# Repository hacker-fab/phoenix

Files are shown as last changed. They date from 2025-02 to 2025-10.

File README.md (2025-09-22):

# phoenix

Phoenix is a tube furnace used for thermal oxidation and annealing.

It uses PID control to follow custom temperature profiles and works on both MicroPython on the ESP32 and a simulated Python desktop environment.

<table>
  <tr>
    <td>
      <br>
      <sub>Fig 1. Tube furnace in action</sub>
    </td>
    <td>
      <br>
      <sub>Fig 2. Simulated PID following a heat profile</sub>
    </td>
    <td>
      <br>
      <sub>Fig 3. Controlling ramp rate to prevent thermal shock</sub>
    </td>
  </tr>
</table>

# Python setup
```bash
python3 -m venv .venv
source .venv/bin/activate
pip install -r requirements.txt
```

# Micropython setup

Install micropython
```bash
https://github.com/micropython/micropython/tree/master/ports/unix#readme
```

Install `typing`
```bash
micropython -m mip install github:josverl/micropython-stubs/mip/typing.mpy
```

Install `udataclasses`
```bash
cd ~/.micropython/lib
# extract src/udataclasses
git clone https://github.com/dhrosa/udataclasses.git tmp
mv tmp/src/udataclasses .
rm -rf tmp
```

# Flash code
```
esptool erase-flash
esptool --baud 460800 write-flash 0 images/ESP32_GENERIC_S3-SPIRAM_OCT-20250809-v1.26.0.bin

mpremote
mpremote connect /dev/ttyUSB0 fs cp main.py :
```
- use the UART port (left side) for flashing
- use the USB port (right side) when using mpremote

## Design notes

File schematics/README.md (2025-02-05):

Reverse engineered schematic based on the code from ProjectsInFlight

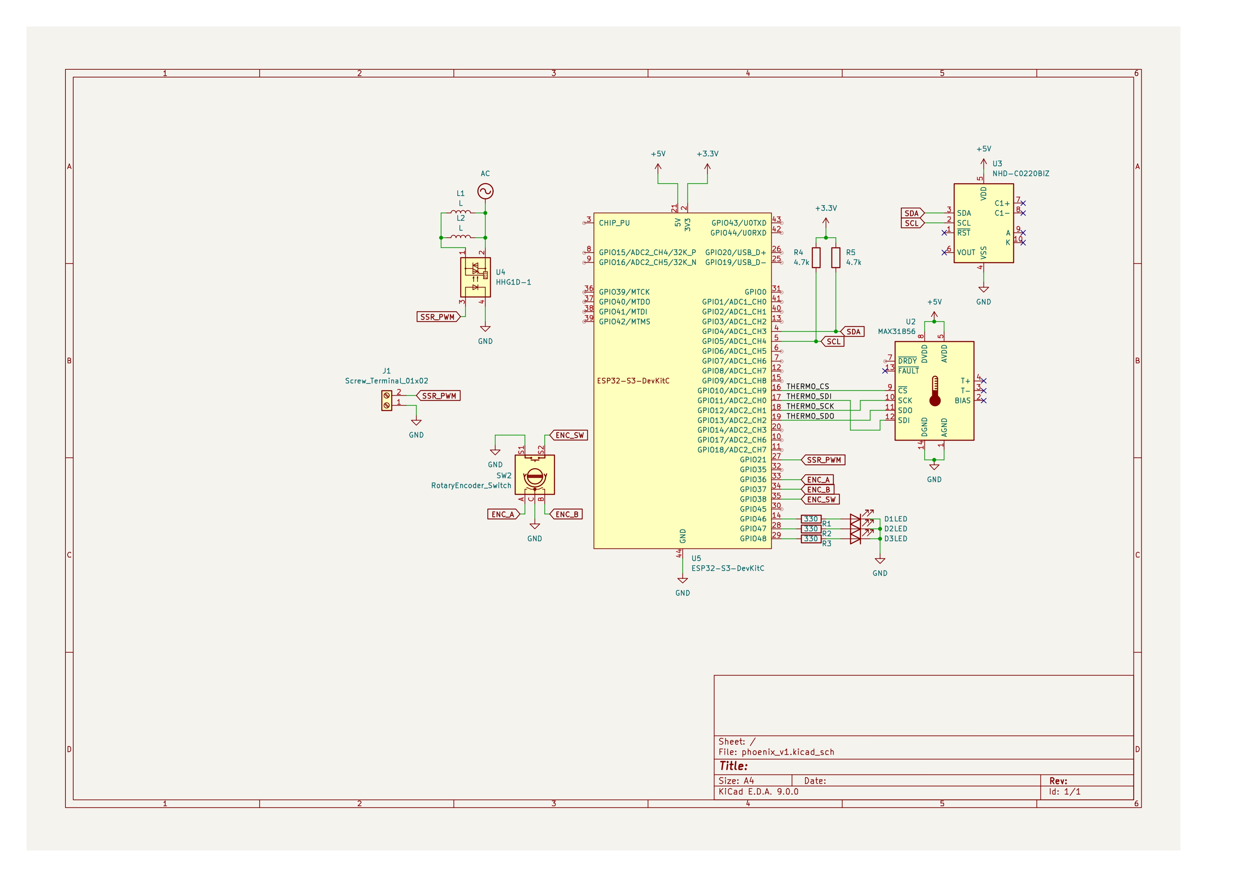
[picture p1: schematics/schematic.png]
schematic image


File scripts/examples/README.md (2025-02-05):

These mini test programs were written while electronics assembly.

1. LCD display.
2. Rotary encoder
    - On press => "button pressed" displayed on LCD.
    - On rotation => value displayed.
3. Thermocouple test
    - should print temp values in Serial console.

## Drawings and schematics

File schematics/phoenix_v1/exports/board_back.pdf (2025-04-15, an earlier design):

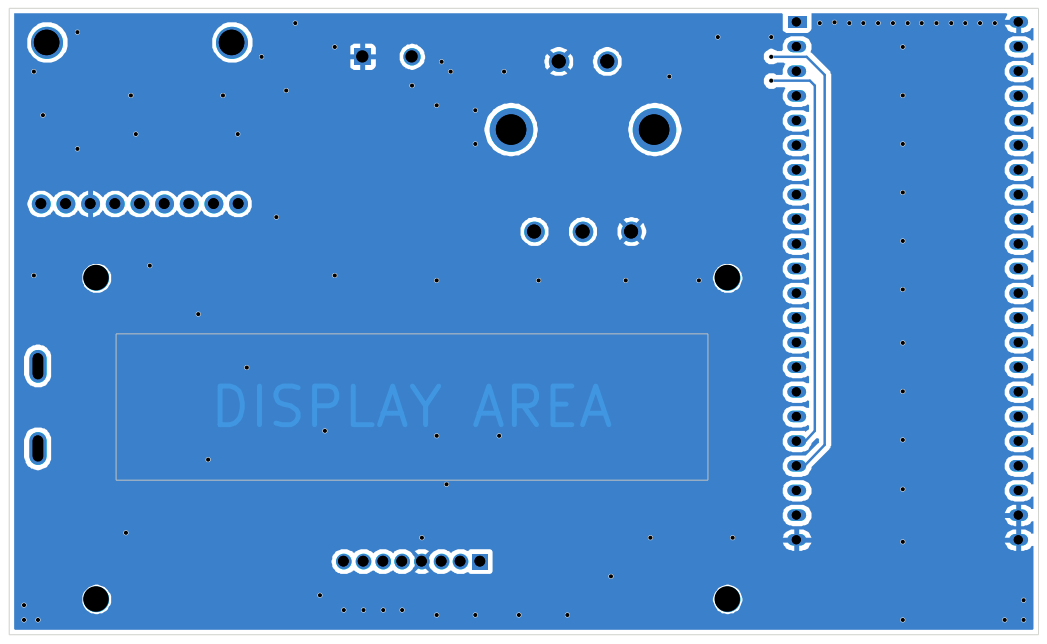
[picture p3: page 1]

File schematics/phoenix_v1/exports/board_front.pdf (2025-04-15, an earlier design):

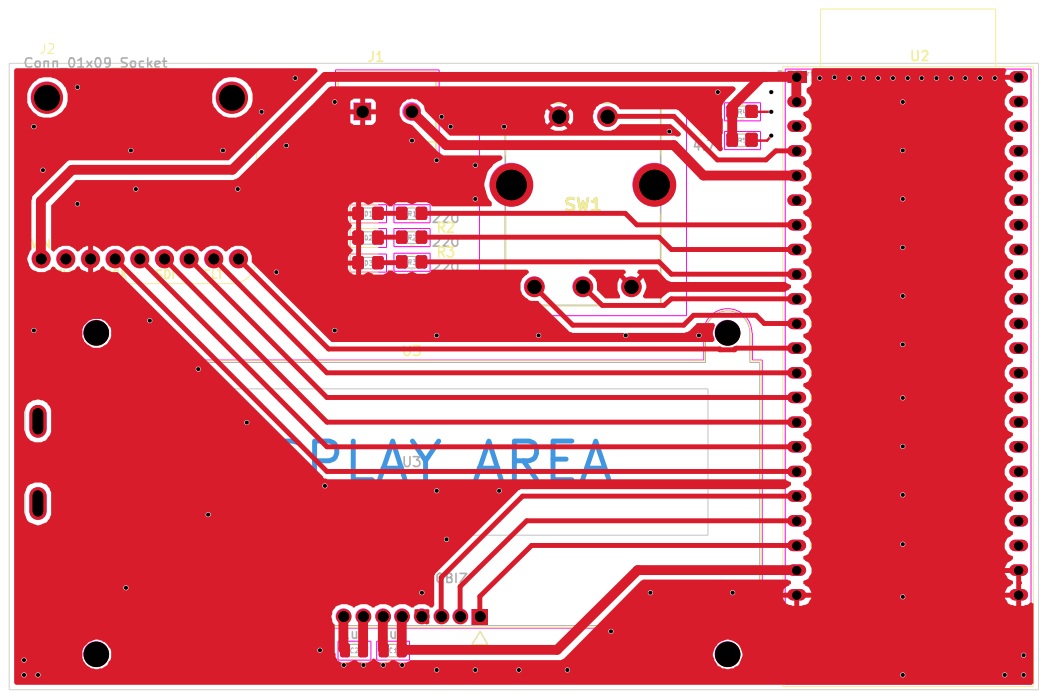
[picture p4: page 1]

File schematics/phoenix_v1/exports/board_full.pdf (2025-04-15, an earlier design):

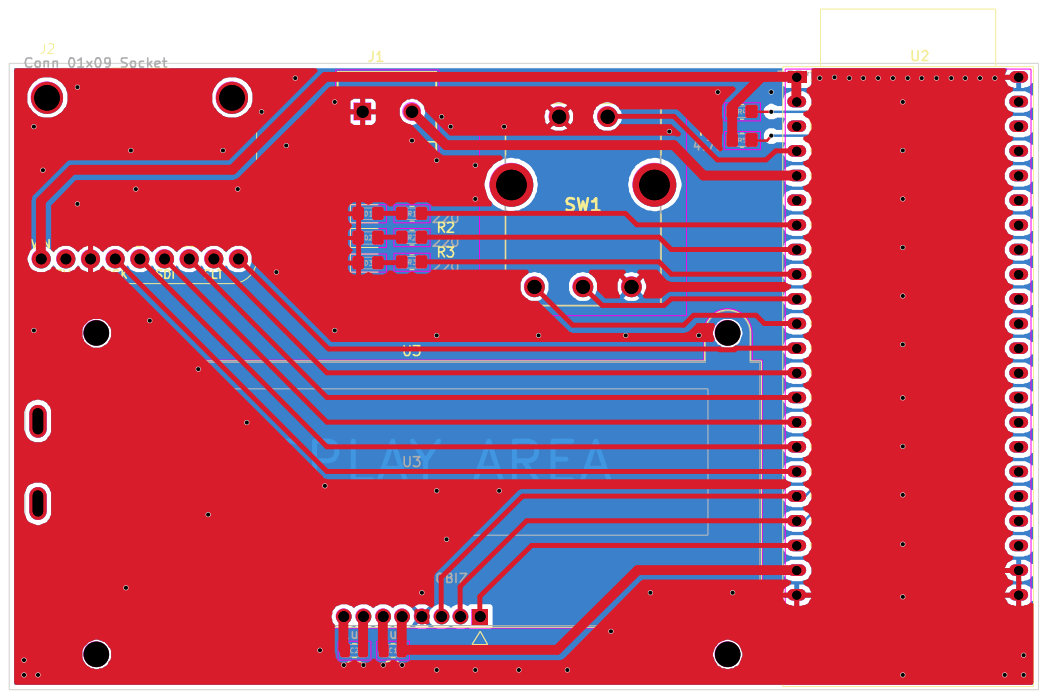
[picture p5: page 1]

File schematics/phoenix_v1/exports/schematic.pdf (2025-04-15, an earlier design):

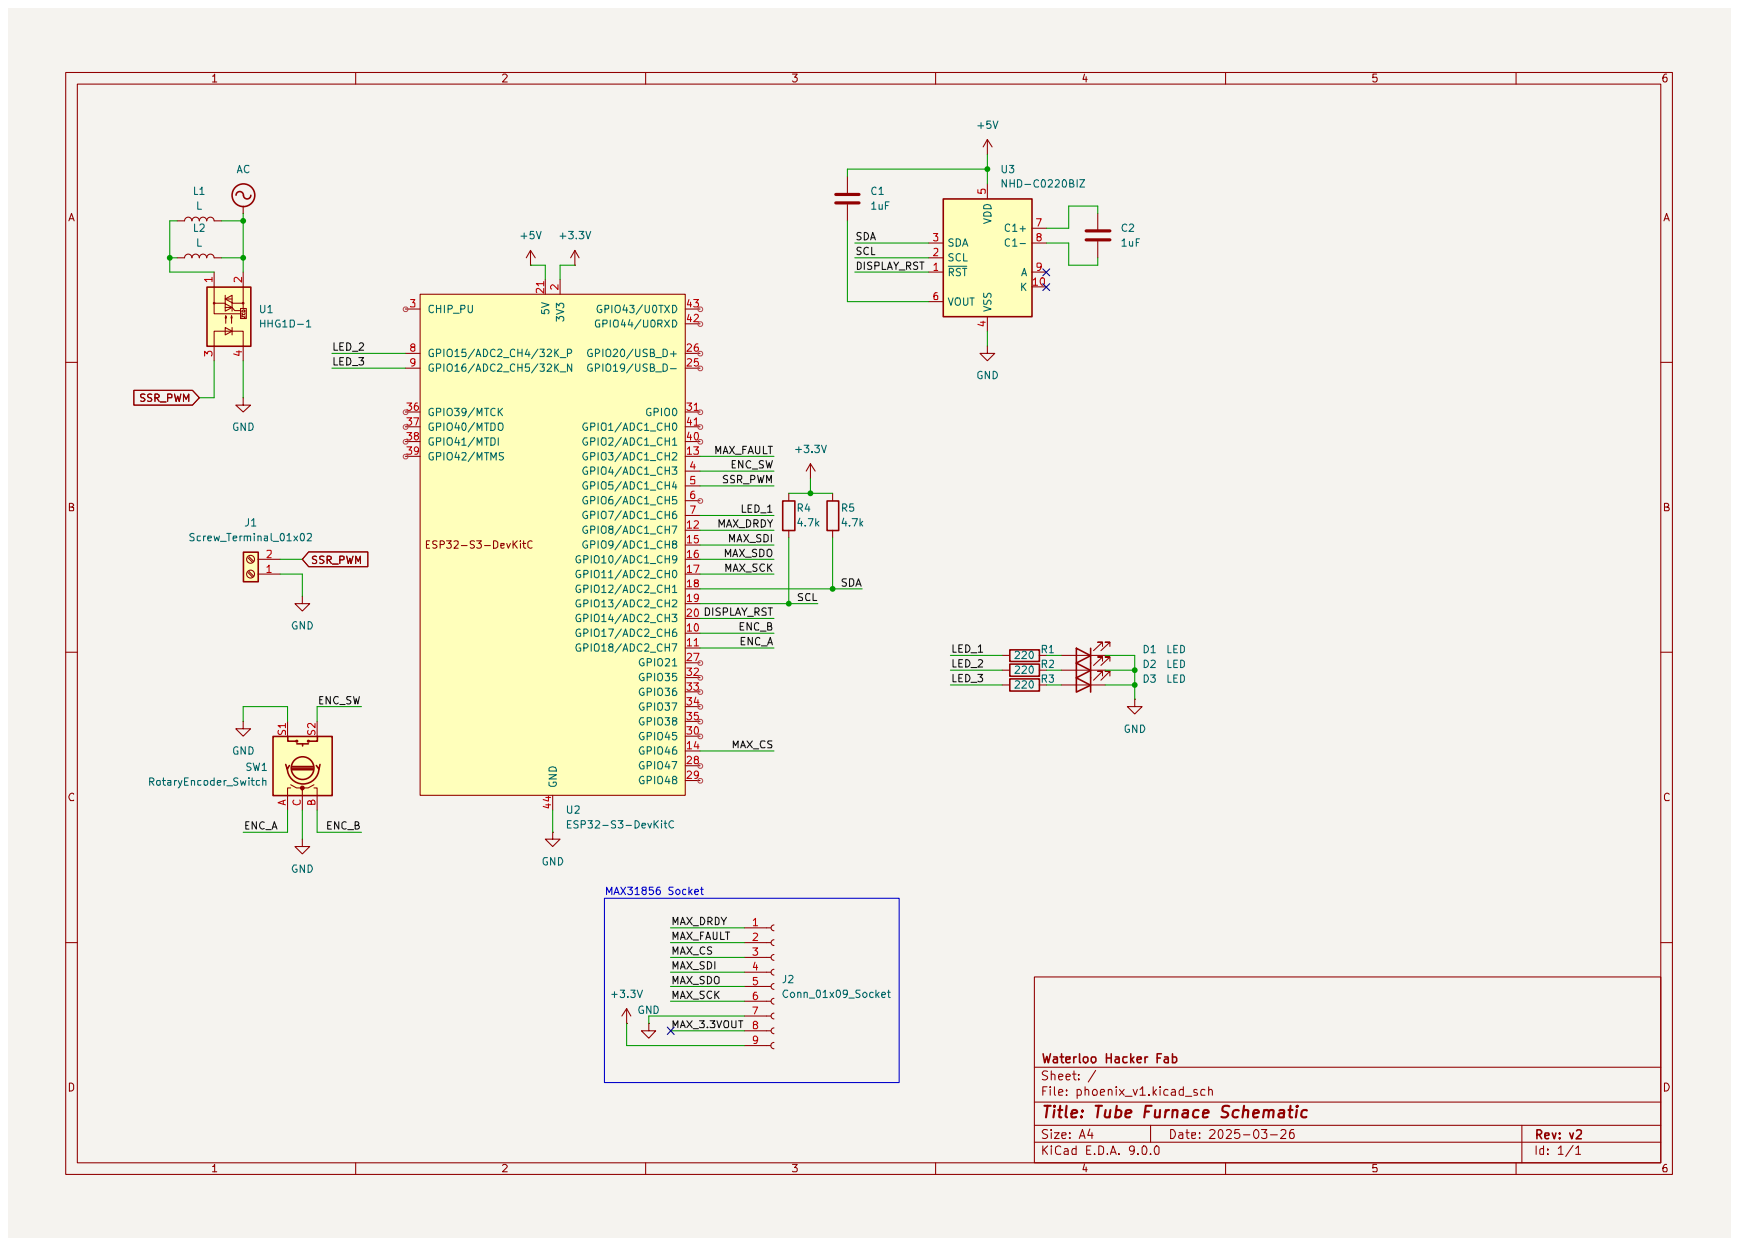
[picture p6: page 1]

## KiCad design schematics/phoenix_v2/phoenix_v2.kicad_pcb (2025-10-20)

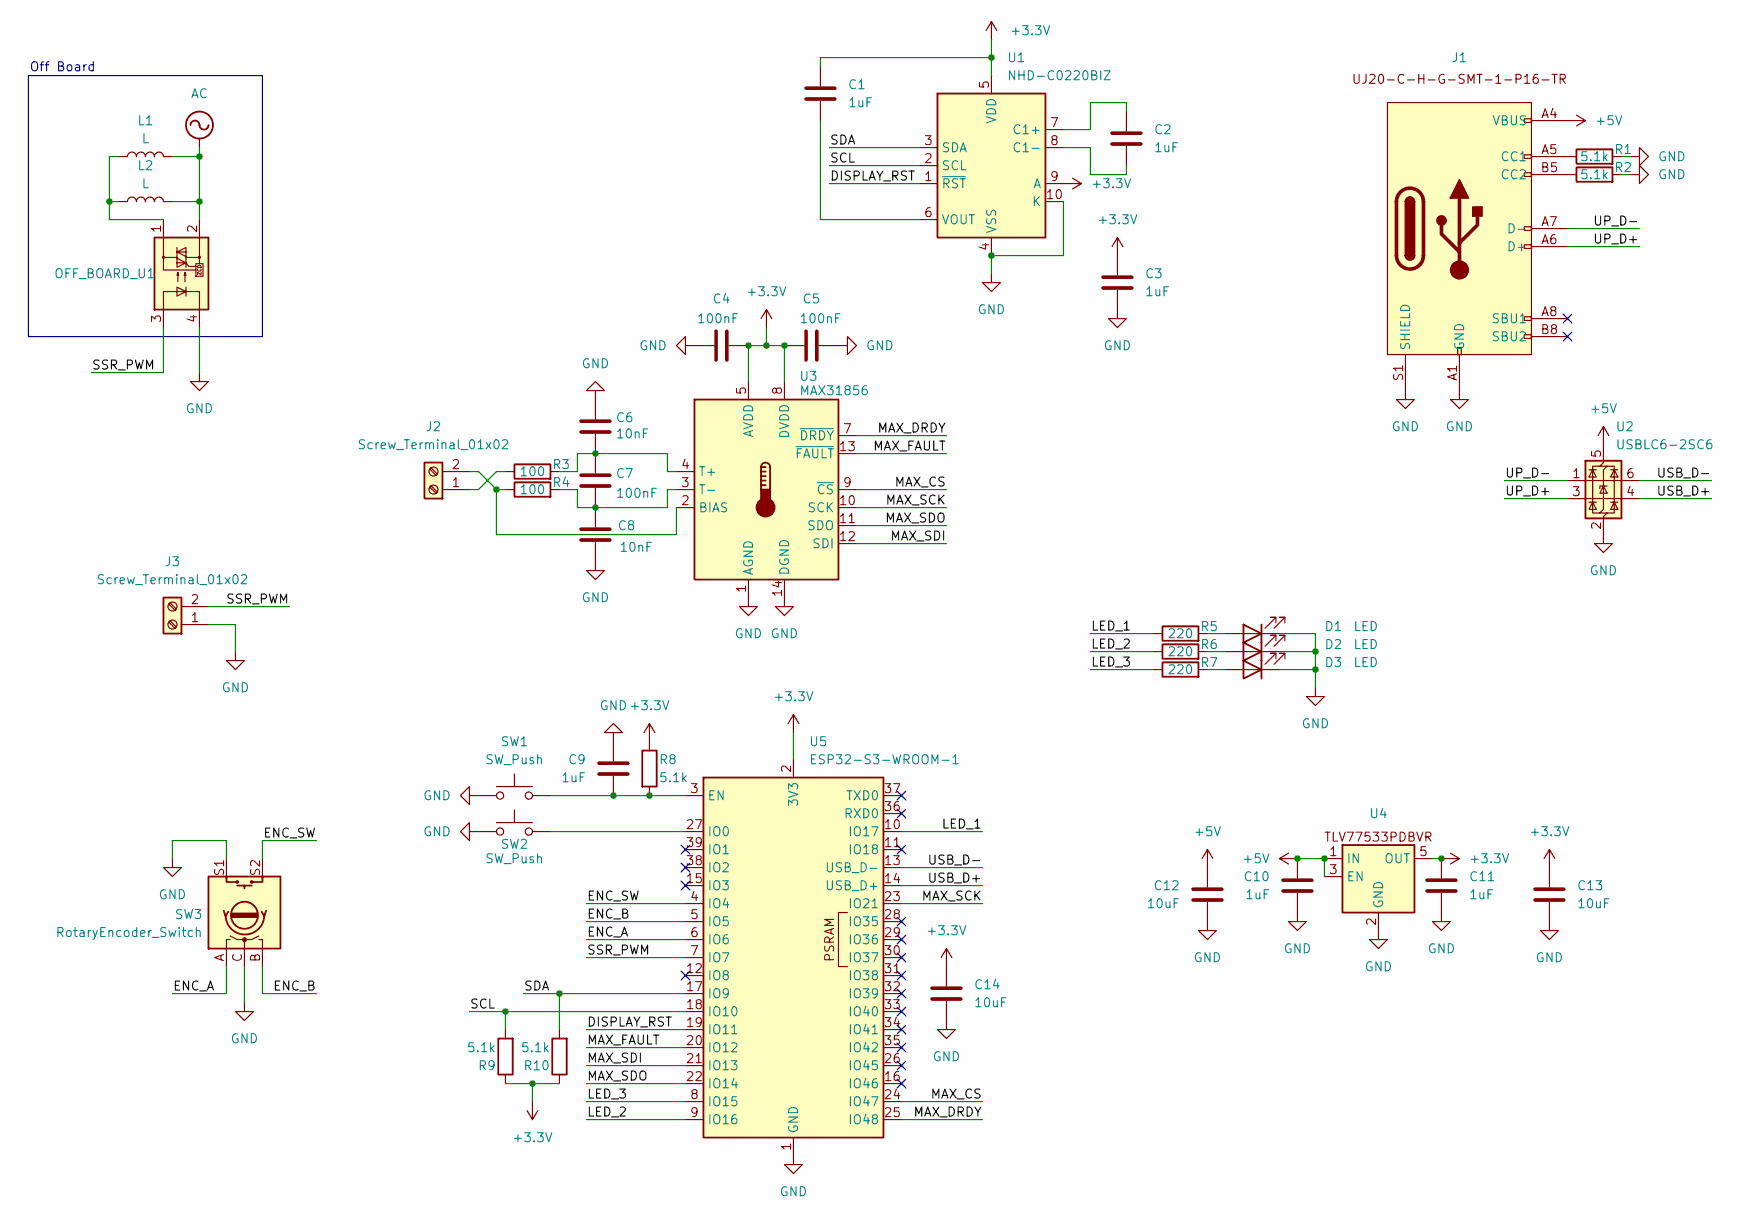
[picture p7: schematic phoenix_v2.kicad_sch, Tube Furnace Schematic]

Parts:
C1, C2, C3, C9, C10, C11: 1uF; C_0805_2012Metric
C4, C5, C7: 100nF; C_0805_2012Metric
C6, C8: 10nF; C_0805_2012Metric
C12, C13, C14: 10uF; C_1206_3216Metric_Pad1.33x1.80mm_HandSolder
D1, D2, D3: LED; D_0805_2012Metric_Pad1.15x1.40mm_HandSolder
J1: UJ20-C-H-G-SMT-1-P16-TR
J2, J3: Screw_Terminal_01x02; TE_282837-2
L1, L2: L
OFF_BOARD_U1: (no value)
R1, R2, R8, R9, R10: 5.1k; R_0805_2012Metric_Pad1.20x1.40mm_HandSolder
R3, R4: 100; R_0805_2012Metric_Pad1.20x1.40mm_HandSolder
R5, R6, R7: 220; R_0805_2012Metric_Pad1.20x1.40mm_HandSolder
SW1, SW2: SW_Push; SW_TH_Tactile_Omron_B3F-102x
SW3: RotaryEncoder_Switch; PEC164120FS0012
U1: NHD-C0220BIZ; NHD-C0220BiZ
U2: USBLC6-2SC6; SOT-23-6
U3: MAX31856; TSSOP-14_4.4x5mm_P0.65mm
U4: SOT-23-5
U5: ESP32-S3-WROOM-1

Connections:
+3.3V: C1.1, C3.1, C4.2, C5.1, C11.1, C13.1, C14.1, R8.1, R9.1, R10.1, U1.5 (VDD), U1.9 (A), U3.5 (AVDD), U3.8 (DVDD), U4.5 (OUT), U5.2 (3V3)
+5V: C10.1, C12.1, J1.A4 (VBUS), J1.A9 (VBUS), J1.B4 (VBUS), J1.B9 (VBUS), U2.5 (VBUS), U4.1 (IN), U4.3 (EN)
/DISPLAY_RST: U1.1 (~RST), U5.19 (IO11)
/ENC_A: SW3.A, U5.6 (IO6)
/ENC_B: SW3.B, U5.5 (IO5)
/ENC_SW: SW3.S2, U5.4 (IO4)
/LED_1: R5.1, U5.10 (IO17)
/LED_2: R6.1, U5.9 (IO16)
/LED_3: R7.1, U5.8 (IO15)
/MAX_CS: U3.9 (~CS), U5.24 (IO47)
/MAX_DRDY: U3.7 (~DRDY), U5.25 (IO48)
/MAX_FAULT: U3.13 (~FAULT), U5.20 (IO12)
/MAX_SCK: U3.10 (SCK), U5.23 (IO21)
/MAX_SDI: U3.12 (SDI), U5.21 (IO13)
/MAX_SDO: U3.11 (SDO), U5.22 (IO14)
/SCL: R9.2, U1.2 (SCL), U5.18 (IO10)
/SDA: R10.2, U1.3 (SDA), U5.17 (IO9)
/SSR_PWM: J3.2, OFF_BOARD_U1.3, U5.7 (IO7)
/UP_D+: J1.A6 (D+), J1.B6 (D+), U2.3 (I/O2)
/UP_D-: J1.A7 (D-), J1.B7 (D-), U2.1 (I/O1)
/USB_D+: U2.4 (I/O2), U5.14 (USB_D+)
/USB_D-: U2.6 (I/O1), U5.13 (USB_D-)
GND: C3.2, C4.1, C5.2, C6.1, C8.2, C9.1, C10.2, C11.2, C12.2, C13.2, C14.2, D1.1 (K), D2.1 (K), D3.1 (K), J1.A1 (GND), J1.A12 (GND), J1.B1 (GND), J1.B12 (GND), J1.S1 (SHIELD), J3.1, OFF_BOARD_U1.4, R1.2, R2.2, SW1.1, SW2.1, SW3.C, SW3.S1, U1.4 (VSS), U1.10 (K), U2.2 (GND), U3.1 (AGND), U3.14 (DGND), U4.2 (GND), U4.4 (NC), U5.1 (GND), U5.40 (GND), U5.41 (GND)
unnamed: D1.2 (A), R5.2
unnamed: D2.2 (A), R6.2
unnamed: D3.2 (A), R7.2
unnamed: J1.A5 (CC1), R1.1
unnamed: J1.B5 (CC2), R2.1
unnamed: J2.1, R3.1
unnamed: J2.2, R4.1, U3.2 (BIAS)
unnamed: L1.1, L2.1, OFF_BOARD_U1.1
unnamed: L1.2, L2.2, OFF_BOARD_U1.2
unnamed: C2.1, U1.7 (C1+)
unnamed: C2.2, U1.8 (C1-)
unnamed: C1.2, U1.6 (VOUT)
unnamed: C6.2, C7.1, R3.2, U3.4 (T+)
unnamed: C7.2, C8.1, R4.2, U3.3 (T-)
unnamed: C9.2, R8.2, SW1.2, U5.3 (EN)
unnamed: SW2.2, U5.27 (IO0)

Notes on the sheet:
Off Board

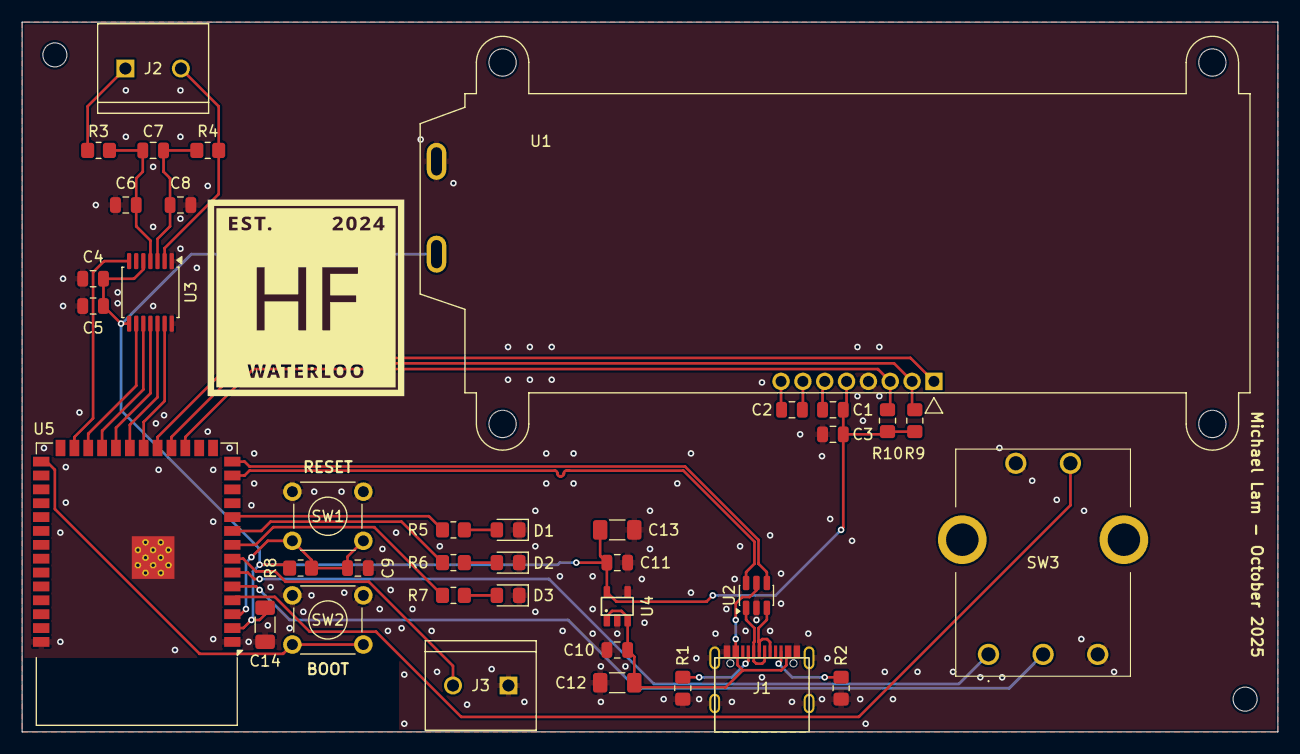
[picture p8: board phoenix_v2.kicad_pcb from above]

Board: 2 copper layers, 115.0 x 65.0 mm, 38 parts (0 on the bottom side), 37 nets.

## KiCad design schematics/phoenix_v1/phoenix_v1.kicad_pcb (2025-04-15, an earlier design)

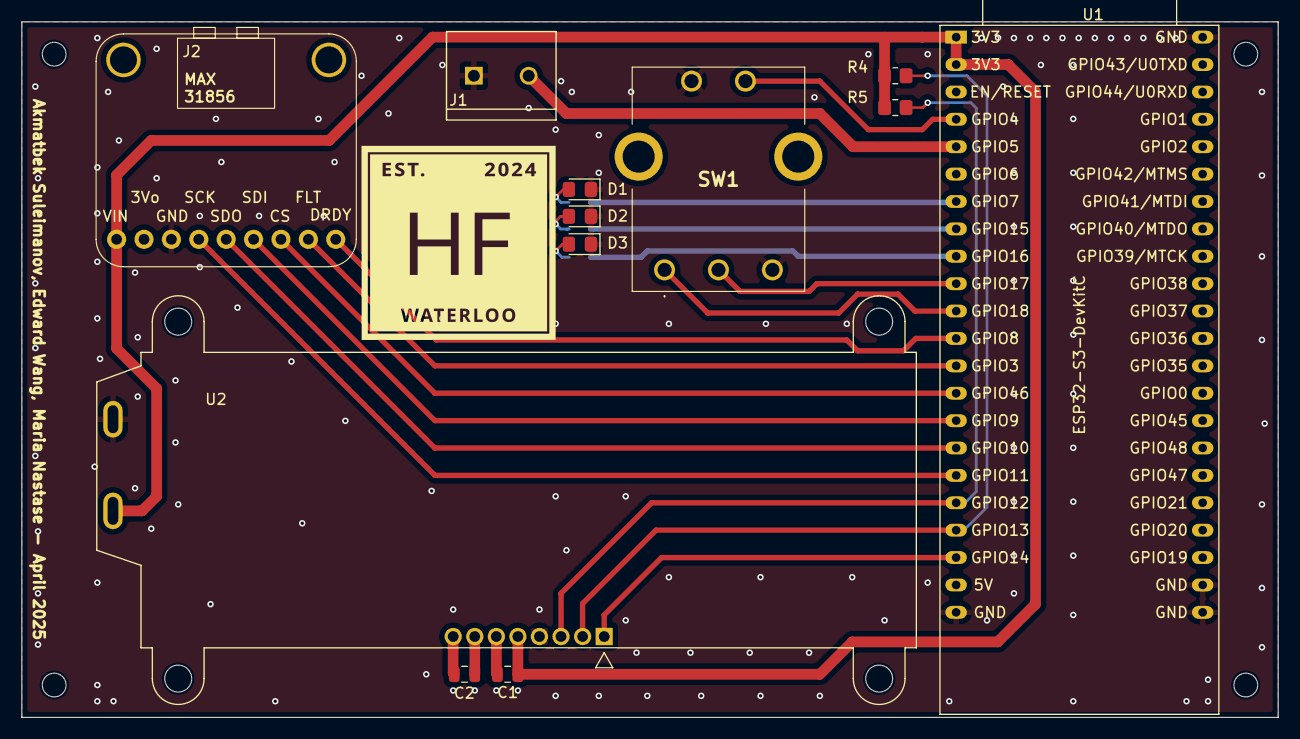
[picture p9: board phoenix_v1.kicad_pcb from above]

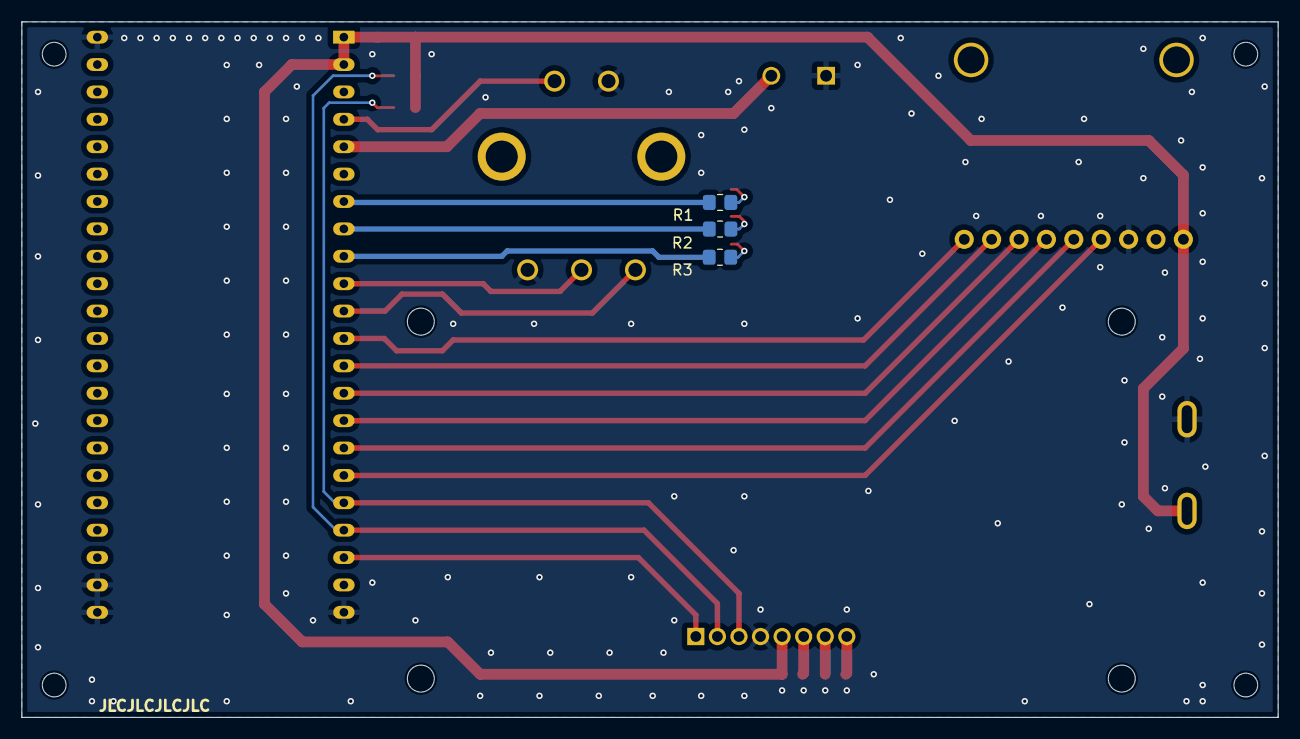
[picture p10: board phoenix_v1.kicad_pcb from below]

Board: 2 copper layers, 116.5 x 64.5 mm, 15 parts (3 on the bottom side), 24 nets.

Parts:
C1, C2: 1uF; C_0805_2012Metric
D1, D2, D3: LED; D_0805_2012Metric_Pad1.15x1.40mm_HandSolder
J1: Screw_Terminal_01x02; TE_282837-2
J2: Conn_01x09_Socket; MAX31856_HEADER
R1, R2, R3: 220; R_0805_2012Metric_Pad1.20x1.40mm_HandSolder
R4, R5: 4.7k; R_0805_2012Metric_Pad1.20x1.40mm_HandSolder
SW1: RotaryEncoder_Switch; PEC164120FS0012
U1: ESP32-S3-DevKitC
U2: NHD-C0220BIZ; NHD-C0220BiZ

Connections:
+3.3V: C1.1, J2.9, R4.1, R5.1, U1.1 (3V3), U1.2 (3V3), U2.5 (VDD), U2.9 (A)
/DISPLAY_RST: U1.20 (GPIO14/ADC2_CH3), U2.1 (~RST)
/ENC_A: SW1.A, U1.11 (GPIO18/ADC2_CH7)
/ENC_B: SW1.B, U1.10 (GPIO17/ADC2_CH6)
/ENC_SW: SW1.S2, U1.4 (GPIO4/ADC1_CH3)
/LED_1: R1.1, U1.7 (GPIO7/ADC1_CH6)
/LED_2: R2.1, U1.8 (GPIO15/ADC2_CH4/32K_P)
/LED_3: R3.1, U1.9 (GPIO16/ADC2_CH5/32K_N)
/MAX_CS: J2.3, U1.14 (GPIO46)
/MAX_DRDY: J2.1, U1.12 (GPIO8/ADC1_CH7)
/MAX_FAULT: J2.2, U1.13 (GPIO3/ADC1_CH2)
/MAX_SCK: J2.6, U1.17 (GPIO11/ADC2_CH0)
/MAX_SDI: J2.4, U1.15 (GPIO9/ADC1_CH8)
/MAX_SDO: J2.5, U1.16 (GPIO10/ADC1_CH9)
/SCL: R4.2, U1.19 (GPIO13/ADC2_CH2), U2.2 (SCL)
/SDA: R5.2, U1.18 (GPIO12/ADC2_CH1), U2.3 (SDA)
/SSR_PWM: J1.2, U1.5 (GPIO5/ADC1_CH4)
GND: D1.1 (K), D2.1 (K), D3.1 (K), J1.1, J2.7, SW1.C, SW1.S1, U1.22 (GND), U1.23 (GND), U1.24 (GND), U1.44 (GND), U2.4 (VSS), U2.10 (K)
unnamed: D1.2 (A), R1.2
unnamed: D2.2 (A), R2.2
unnamed: D3.2 (A), R3.2
unnamed: C2.1, U2.7 (C1+)
unnamed: C2.2, U2.8 (C1-)
unnamed: C1.2, U2.6 (VOUT)

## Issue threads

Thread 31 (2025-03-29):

fix top trace too big

wang-edward, 2025-03-29:

Closed 2025-04-16.

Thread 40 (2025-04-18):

take measurements

wang-edward, 2025-04-18:
to get max_heating_rate:
- plug in thermocouple
- set PWM to 100%
- record temp / time
  - consider thermal intertia. the earlier measurements might not be representative

to get cooling_coefficient:
- Heat to some temp (i.e. 1000C)
- stabilize the temperature
- record ambient temperature
- set PWM to 0%
- record temp / time
  - $T(t)=T_{\text{ambient}}  + (T(0)−T_{\text{ambient}} ) \cdot e^{−kt}$
  - where $T(0)$ is the target temp (i.e. 1000C)
- Also need to convert sim.py to use exponential model

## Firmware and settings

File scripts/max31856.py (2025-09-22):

#The MIT License (MIT)
#
#Copyright (c) 2016 Alin Baltaru-Agud
#
#Permission is hereby granted, free of charge, to any person obtaining a copy
#of this software and associated documentation files (the "Software"), to deal
#in the Software without restriction, including without limitation the rights
#to use, copy, modify, merge, publish, distribute, sublicense, and/or sell
#copies of the Software, and to permit persons to whom the Software is
#furnished to do so, subject to the following conditions:
#
#The above copyright notice and this permission notice shall be included in all
#copies or substantial portions of the Software.
#
#THE SOFTWARE IS PROVIDED "AS IS", WITHOUT WARRANTY OF ANY KIND, EXPRESS OR
#IMPLIED, INCLUDING BUT NOT LIMITED TO THE WARRANTIES OF MERCHANTABILITY,
#FITNESS FOR A PARTICULAR PURPOSE AND NONINFRINGEMENT. IN NO EVENT SHALL THE
#AUTHORS OR COPYRIGHT HOLDERS BE LIABLE FOR ANY CLAIM, DAMAGES OR OTHER
#LIABILITY, WHETHER IN AN ACTION OF CONTRACT, TORT OR OTHERWISE, ARISING FROM,
#OUT OF OR IN CONNECTION WITH THE SOFTWARE OR THE USE OR OTHER DEALINGS IN THE
#SOFTWARE.


import time
import math
import machine

class max31856(object):
	"""Read Temperature on the Feather HUZZAH ESP8266 from the MAX31856 chip using GPIO
	   Connections will use the hardware SPI interface on the ESP8266 to talk to the MAX31855 sensor.
	   Tested with: MicroPython 1.8.5 on ESP8266: esp8266-20161017-v1.8.5.bin
	"""

	def __init__(self, csPin = 15, misoPin = 12, mosiPin = 13, clkPin = 14):
		self.csPin = csPin
		self.misoPin = misoPin
		self.mosiPin = mosiPin
		self.clkPin = clkPin
		self.setupGPIO()
		#
		# Config Register 2
		# ------------------
		# bit 7: Reserved                                -> 0 
		# bit 6: Averaging Mode 1 Sample                 -> 0 (default)
		# bit 5: Averaging Mode 1 Sample                 -> 0 (default)
		# bit 4: Averaging Mode 1 Sample                 -> 0 (default)
		# bit 3: Thermocouple Type -> K Type (default)   -> 0 (default)
		# bit 2: Thermocouple Type -> K Type (default)   -> 0 (default)
		# bit 1: Thermocouple Type -> K Type (default)   -> 1 (default)
		# bit 0: Thermocouple Type -> K Type (default)   -> 1 (default)
		#
		self.writeRegister(1, 0x03)
		
	def setupGPIO(self):
		machine.Pin(self.csPin, machine.Pin.OUT)
		machine.Pin(self.misoPin, machine.Pin.IN)
		machine.Pin(self.mosiPin, machine.Pin.OUT)
		machine.Pin(self.clkPin, machine.Pin.OUT)

		machine.Pin(self.csPin).value(1)
		machine.Pin(self.clkPin).value(0)
		machine.Pin(self.mosiPin).value(0)
	
	def readThermocoupleTemp(self):
		self.requestTempConv()

		# read 4 registers starting with register 12
		out = self.readRegisters(0x0c, 4) 
		
		[tc_highByte, tc_middleByte, tc_lowByte] = [out[0], out[1], out[2]]	
		temp = ((tc_highByte << 16) | (tc_middleByte << 8) | tc_lowByte) >> 5
		
		if (tc_highByte & 0x80):
			temp -= 0x80000
		
		temp_C = temp * 0.0078125
		
		fault = out[3]
		
		if ((fault & 0x80) == 1):
			raise FaultError("Cold Junction Out-of-Range")
		if ((fault & 0x40) == 1):
			raise FaultError("Thermocouple Out-of-Range")
		if ((fault & 0x20) == 1):
			raise FaultError("Cold-Junction High Fault")
		if ((fault & 0x10) == 1):
			raise FaultError("Cold-Junction Low Fault")
		if ((fault & 0x08) == 1):
			raise FaultError("Thermocouple Temperature High Fault")
		if ((fault & 0x04) == 1):
			raise FaultError("Thermocouple Temperature Low Fault")
		if ((fault & 0x02) == 1):
			raise FaultError("Overvoltage or Undervoltage Input Fault")
		if ((fault & 0x01) == 1):
			raise FaultError("Thermocouple Open-Circuit Fault")
				
		return temp_C
				
	def readJunctionTemp(self):
		self.requestTempConv()
		
		# read 3 registers starting with register 9
		out = self.readRegisters(0x09, 3)
		
		offset = out[0]
		
		[junc_msb, junc_lsb] = [out[1], out[2]]
		
		temp = ((junc_msb << 8) | junc_lsb) >> 2
		temp = offset + temp
		
		if (junc_msb & 0x80):
			temp -= 0x4000
		
		temp_C = temp * 0.015625
		
		return temp_C
	
	def requestTempConv(self):
		#
		# Config Register 1
		# ------------------
		# bit 7: Conversion Mode                         -> 0 (Normally Off Mode)
		# bit 6: 1-shot                                  -> 1 (ON)
		# bit 5: open-circuit fault detection            -> 0 (off)
		# bit 4: open-circuit fault detection            -> 0 (off)
		# bit 3: Cold-junction temerature sensor enabled -> 0 (default)
		# bit 2: Fault Mode                              -> 0 (default)
		# bit 1: fault status clear                      -> 1 (clear any fault)
		# bit 0: 50/60 Hz filter select                  -> 0 (60Hz)
		#
		# write config register 0
		self.writeRegister(0, 0x42)
		# conversion time is less than 150ms
		time.sleep(.2) #give it 200ms for conversion

	def writeRegister(self, regNum, dataByte):
		machine.Pin(self.csPin).value(0)
		
		# 0x8x to specify 'write register value'
		addressByte = 0x80 | regNum;
		
		# first byte is address byte
		self.sendByte(addressByte)
		# the rest are data bytes
		self.sendByte(dataByte)

		machine.Pin(self.csPin).value(1)

		
	def readRegisters(self, regNumStart, numRegisters):
		out = []
		machine.Pin(self.csPin).value(0)
		
		# 0x to specify 'read register value'
		self.sendByte(regNumStart)
		
		for byte in range(numRegisters):	
			data = self.recvByte()
			out.append(data)

		machine.Pin(self.csPin).value(1)
		return out

	def sendByte(self,byte):
		for bit in range(8):
			machine.Pin(self.clkPin).value(1)
			if (byte & 0x80):
				machine.Pin(self.mosiPin).value(1)
			else:
				machine.Pin(self.mosiPin).value(0)
			byte <<= 1
			machine.Pin(self.clkPin).value(0)

	def recvByte(self):
		byte = 0x00
		for bit in range(8):
			machine.Pin(self.clkPin).value(1)
			byte <<= 1
			if machine.Pin(self.misoPin).value():
				byte |= 0x1
			machine.Pin(self.clkPin).value(0)
		return byte	

class FaultError(Exception):
	pass

	
if __name__ == "__main__":
    # master / slave are from the perspective of the MAX31856
    PIN_CS = 46
    PIN_MISO = 10 # SDO trace
    PIN_MOSI = 9 # SDI trace
    PIN_CLK = 11

    max = max31856(PIN_CS, PIN_MISO, PIN_MOSI, PIN_CLK)
     
    while True:
        temp_thermo = max.readThermocoupleTemp()
        temp_junction = max.readJunctionTemp()
        print(f"Thermocouple temp: {temp_thermo}, Cold junction temp: {temp_junction}")

        time.sleep(0.1)

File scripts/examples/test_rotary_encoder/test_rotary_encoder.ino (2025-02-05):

#include <LiquidCrystal_I2C.h>

// Pin definitions for rotary encoder
#define CLK 2  // Clock pin
#define DT 3   // Data pin
#define SW 4   // Switch pin

// LCD setup
LiquidCrystal_I2C lcd(0x27, 16, 2);  // I2C address 0x27, 16 column and 2 rows

// Encoder variables
volatile int counter = 0;  // Current "position" of encoder
volatile bool needsUpdate = false;  // Flag to indicate when display should update
volatile unsigned long lastButtonPress = 0;
volatile unsigned long lastEncoderISR = 0;  // For encoder debouncing
int temperature = 1000;    // Starting temperature
String currentDir = "";

void setup() {
  Serial.begin(115200);  // Initialize serial for debugging
  
  // Initialize LCD
  lcd.init();
  lcd.backlight();
  
  // Set up encoder pins
  pinMode(CLK, INPUT);
  pinMode(DT, INPUT);
  pinMode(SW, INPUT_PULLUP);
  
  // Initial pin state
  attachInterrupt(digitalPinToInterrupt(CLK), updateEncoder, CHANGE);
  
  // Initial display
  updateDisplay();
}

void updateEncoder() {
  // Simple debounce in ISR
  unsigned long now = millis();
  if (now - lastEncoderISR < 5) {  // 5ms debounce
    return;
  }
  lastEncoderISR = now;
  
  // Read the current state of CLK
  if (digitalRead(CLK) == HIGH) {
    // If DT state is different from CLK state then
    // encoder is rotating clockwise
    if (digitalRead(DT) == LOW) {
      counter++;
      if (counter > 20) counter = 20;  // Limit for 1200°C
    } else {
      counter--;
      if (counter < -99) counter = -99;  // Limit for 10°C
    }
    needsUpdate = true;  // Set flag to indicate display needs updating
  }
}

void updateDisplay() {
  // Calculate temperature based on counter
  temperature = 1000 + (counter * 10);
  
  // Ensure temperature stays within bounds
  if (temperature > 1200) temperature = 1200;
  if (temperature < 10) temperature = 10;
  
  lcd.clear();
  lcd.setCursor(0, 0);
  lcd.print("Temp: ");
  lcd.print(temperature);
  lcd.print((char)223);  // Degree symbol
  lcd.print("C");
  
  lcd.setCursor(0, 1);
  lcd.print("Count: ");
  lcd.print(counter);
  
  // Debug output
  Serial.print("Counter: ");
  Serial.print(counter);
  Serial.print(" Temp: ");
  Serial.println(temperature);
}

void checkButton() {
  bool buttonState = digitalRead(SW);
  
  if (buttonState == LOW) {
    // Button is pressed
    if (millis() - lastButtonPress > 50) {  // Debounce
      lcd.clear();
      lcd.setCursor(0, 0);
      lcd.print("Button Pressed!");
      Serial.println("Button pressed!");
      delay(500);
      updateDisplay();  // Restore normal display
      lastButtonPress = millis();
    }
  }
}

void loop() {
  // Only update display when encoder has changed
  if (needsUpdate) {
    updateDisplay();
    needsUpdate = false;  // Reset the flag
  }
  
  checkButton();  // Check for button presses
  delay(10);      // Small delay to prevent button bounce
}

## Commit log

2025-02-05 rename src -> TubeFurnace
2025-02-05 build in ci (#3)
    * test
    * matrix and ls
    * fix path
    * fix path 2
    * install avr
    * update index
    * delete debug print
    * cleanup chatgpt comments
    * cleanup job name
2025-02-27 relay test script (#12)
2025-02-27 rename kicad project to v0 (#13)
    * gitignore
    * rename to v0
    [phoenix.kicad_pcb, phoenix.kicad_sch]
2025-03-01 add esp32 libraries
    [phoenix_v1.kicad_pcb, phoenix_v1.kicad_sch]
2025-03-08 update test_thermocouple for esp32 (#16)
    * update for esp32
    * comment
2025-03-10 v1 schematic (#14)
    * v1 schematic
    * screw terminal
    * update screnshot
    ---------
    [phoenix_v1.kicad_sch]
2025-03-21 assign footprints (#17)
    * layout
    * fix duplicate
    * max31856 socket
    * add ncs
    * upload screw terminal files
    * footprint assignment
    * upload MAX31856 eagle-converted source
    * create custom footprint for MAX31856 header
    * upload pec stuff
    * use project footprint library
    * extract PEC footprint and sym
    * finish assigning footprints and update PCB
    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
    [phoenix_v1.kicad_pcb, phoenix_v1.kicad_sch]
2025-03-21 exclude relay and inductors from board (#18)
    [phoenix_v1.kicad_sch]
2025-03-21 set R for leds (#19)
    [phoenix_v1.kicad_sch]
2025-03-21 reannotate (#20)
    [phoenix_v1.kicad_sch]
2025-03-21 caps for display (#21)
    [phoenix_v1.kicad_pcb, phoenix_v1.kicad_sch]
2025-03-21 kiri setup (#23)
    * first try
    * upload pages v3
    * better title
    * try kiri instead
    * checkout v4?
    * reddragon version
    * try branch
    * use fork with upload v4
    * random diff to trigger run
    * ref
    * try overall checkout v2
    * go back
    * retrigger
    * 1.0
    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
2025-03-22 arrange stuff and draw outline (#25)
    * show which direction MAX is facing
    * arrange and draw outline
    * better alignment
    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
    [phoenix_v1.kicad_pcb]
2025-03-22 fix encoder footprint and label mismatch (#26)
    [phoenix_v1.kicad_pcb, phoenix_v1.kicad_sch]
2025-03-22 fix max footprint (#27)
    * delete extra stuff on max breakout footprint
    * update on pcb
    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
    [phoenix_v1.kicad_pcb]
2025-04-15 routing (#28)
    * make board outline silkscreen instead of edgecuts
    * some wiring
    * update pcb for max footprint
    * cleanup max header
    * route everything and GND fill and via stitch
    * title blocks
    * export pdfs
    * fix "Dont mix global and local net labels for the same net (SSR_PWM)"
    * fix "it should be made clear on the schematic that U1 and surrounding components are off board"
    * fix "NHD-CO22BIZ needs 3.3V not 5V"
    * connect A and K on lcd
    * fix "routing for the I2C pullups VDD trace"
    * fix "more space on display mounting holes"
    * upload DRU
    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
    [phoenix_v1-B_Cu.gbr, phoenix_v1-B_Mask.gbr, phoenix_v1-B_Paste.gbr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]
2025-04-16 rewrite pid in python (#34)
    * requirements
    * chat... gpt...
    * improvement
    * python gitignore
    * req.txt
    * split out running_average
    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
2025-04-16 only run kiri when schematics/* is changed (#37)
2025-04-18 follow heat curve (#39)
    * use heat profile
    * autoformat
    * test profile
    * validate profile test
    * autoformat
2025-09-08 cleanup (#49)
    * delete arduino stuff
    * update workflows
    * fix paths
    * fix paths 2
    * move ino scripts to scripts/examples/
    * only test when real files have changed
    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
    [test_lcd.ino, test_rotary_encoder.ino]
2025-09-22 start writing hw examples in scripts/ (#50)
    * try out leds
    * fix formatting
    * rename stuff, add lcd.c and got lcd.py scan() working
    * wip
    * found docs on Co and RS
    * try running my thing and also a chat gpt attempt
    * temp
    * refactor scripts.py
    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
    [lcd.c, lcd.py, led.py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]
2025-09-22 Implement Rotary Encoder driver with interrupts (#52)
    * [encoder] Implement Rotary Encoder driver with interrupts (on esp32-s3-devkitm-1)
    * update pin mappings for real HW
    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
2025-10-09 [lcd] Implement I2C driver (ST7036) + test for NHD‑C0220BiZ display (#55)
2025-10-16 New PCB Version and LCD Driver Fix
    [phoenix_v2-B_Cu.gbr, phoenix_v2-B_Mask.gbr, phoenix_v2-B_Paste.gbr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]
2025-10-20 Changed decoupling capacitor value for ESP32-S3
    [phoenix_v2.kicad_sch]
2025-10-20 Forgot to change capacitor size
    [phoenix_v2.kicad_pcb, phoenix_v2.kicad_sch]
2025-10-20 Mounting Holes missing + Update Gerber
    [phoenix_v2-B_Cu.gbr, phoenix_v2-B_Mask.gbr, phoenix_v2-B_Paste.gbr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]
